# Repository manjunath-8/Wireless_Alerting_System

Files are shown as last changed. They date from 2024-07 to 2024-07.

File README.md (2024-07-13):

# Wireless Alerting System
## Abstract
This project presents the development and implementation of a wireless dashboard for real-time machine error monitoring using the Arduino IoT Cloud. The system aims to enhance operational efficiency and streamline error resolution across multiple departments within an industrial setting. Utilizing ESP32 microcontrollers, the dashboard collects and transmits machine error data wirelessly, providing instant updates accessible via mobile devices and desktops. The project features a custom-designed PCB and a 3D-printed case to house the electronics. Key functionalities include department-wide error dashboards, efficiency tracking using Google Sheets, and mobile accessibility for on-the-go monitoring. This innovative solution facilitates proactive maintenance, minimizes downtime, and improves overall productivity.

## Repository Structure
### Codes
This section contains the code necessary for the operation of the Wireless Alerting System. The repository is organized into two main subdirectories: Arduino IoT Cloud Sketch and Google Sheets App Script.

- **Arduino_IoT_Cloud**
In this subdirectory, you will find the code to be uploaded to the ESP32 microcontroller using the Arduino IoT Cloud platform. The code handles the collection of machine error data and its transmission to the cloud.
- **Google_Sheets_App_Script**
This subdirectory contains the Google Sheets App Script code, which is used to track efficiency and log machine errors in a Google Sheet.

### PCB Design Files
Schematic and layout files for the custom PCB design, including BOM (Bill of Materials) and Gerber files for manufacturing.
  
### Fusion360
STL files for 3D printing the custom-designed case for the electronics.

**Note:** Refer PPT, Report, Poster for other details. 

## Setting Up Arduino IoT Cloud

### 1. Adding Devices and Programming with Arduino IoT Cloud

1. **Create an Account and Setup**
   - Sign up for an Arduino IoT Cloud account if you haven't already.

2. **Create a New Thing**
   - Log into Arduino IoT Cloud.
   - Click on "Things" and then "Create a New Thing".
   - Name your device (e.g., ESP32), select the board (ESP32), and choose a connectivity type (Wi-Fi).

3. **Setting Up Variables**
   - Define variables for your project (e.g., error codes, timestamps).
   - Specify data types and any default values.

4. **Create Dashboards**
   - Design dashboards to visualize your variables in real-time.
   - Arrange widgets to display machine error data effectively.

5. **Programming the ESP32**
   - Write your Arduino sketch (`Arduino_IoT_Cloud_Sketch`) to read sensor data (e.g., machine error data) and update variables.
   - Use the Arduino IDE or Arduino IoT Cloud's online editor to upload your sketch to the ESP32.

6. **Testing**
   - Ensure your ESP32 is connected to Wi-Fi and transmitting data correctly.
   - Monitor the Arduino IoT Cloud dashboard to verify data reception.

## Integrating with Google Sheets App Script

### 2. Writing and Deploying Google Sheets App Scripts

1. **Create a Google Sheet**
   - Open Google Sheets and create a new spreadsheet.
   - Set up columns for error logs, timestamps, and any other relevant data.

2. **Enable Google Apps Script**
   - In Google Sheets, go to "Extensions" > "Apps Script" to open the script editor.

3. **Write the Error Logger Script**
   - Write a script (`Google_Sheets_App_Script`) to receive data from Arduino IoT Cloud.
   - Use functions like `doPost(e)` to handle incoming data via HTTP requests.
   - Parse incoming data and append it to your Google Sheets.
   
4. **Deploy the Scripts**
   - Save and deploy your scripts as a web app.
   - Set permissions to run the script as you (the owner) or anyone accessing the web app.
   - Obtain the deployment URL for later use in your Arduino IoT Cloud setup.

# Integration and Testing

1. **Connect Arduino IoT Cloud to Google Sheets**
   - Use the deployment URL of your Google Apps Script in Arduino IoT Cloud.
   - Configure the HTTP integration to send data from Arduino IoT Cloud to your Google Sheets App Script endpoint.

2. **Monitor and Debug**
   - Test the entire system to ensure data flows from ESP32 → Arduino IoT Cloud → Google Sheets correctly.
   - Use debugging tools in Arduino IoT Cloud and Google Sheets to troubleshoot any issues.

By following these steps, you can successfully integrate your Arduino IoT Cloud setup with Google Sheets, allowing for real-time logging and dashboarding of machine error data.

## License
This project is licensed under the MIT License - see the [LICENSE](LICENSE) file for details.

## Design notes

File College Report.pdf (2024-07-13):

## School of Electronics and Communication Engineering

## Minor-I Project Report

on

# WIRELESS ALERTING SYSTEM FOR INDUSTRIAL ENVIRONMENT

By:

1. Goutami Naragund | USN:01FE21BEC177
2. Manjunath Inamati | USN:01FE21BEC356
3. Chetan Paranatti | USN:01FE21BEC163

## Semester: VI, 2023-2024

## Under the Guidance of

## Saroja V Siddamal

1

KLE Technological University,

### HUBBALLL580031

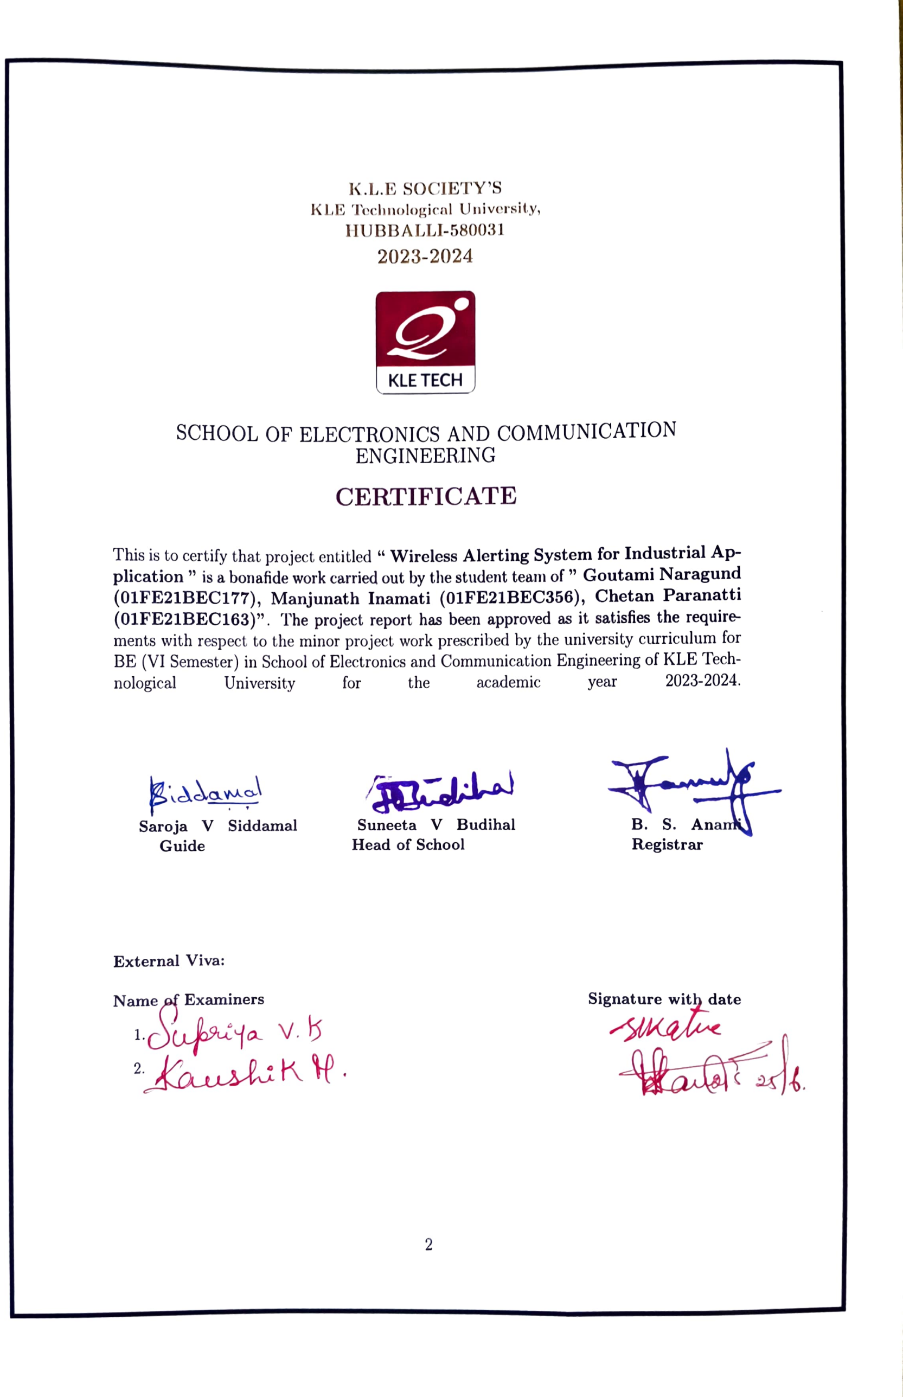
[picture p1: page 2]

# Badamal

### Saroja V Siddamal

Guide

# SCHOOL OF ELECTRONICS AND COMMUNICATION

## ENGINEERING

External Viva:

K.L.E SOCIETY'S

### Name af Examiners

This is to certify that project entitled 4 Wireless Alerting System for Industrial Ap plication " is a bonafide work carried out by the student team of " Goutami Naragund (01FE21BEC177), Manjunath Inamati (0IFE21BEC356), Chetan Paranatti

# (01FE21BEC163)". The project report has been approved as it satisfies the require

# ments with respect to the minor project work prescribed by the university curriculum for

# BE (VI Semester) in School of Electronics and Communication Engineering of KLE Tech

nological | University | for | the | academic

2023-2024

### KLE TECH

# dufaiya v.b

Kaushik .

# CERTIFICATE

Suneeta V Budihal
Head of School

2

year

### B. S. Anan

## Registrar

## Signature with date

2023-2024.

## ACKNOWLEDGMENT

We express our gratitude to the faculty and management for their professional guidance throughout the project’s completion. We would like to extend our thanks to Dr. Ashok Shettar, Vice-Chancellor at KLE Technological University, Hubballi, for their visionary leadership and unwavering support. Special thanks to Dr. Suneeta V Budihal, Professor and Head of SoECE, for providing us with direction and fostering our skills and academic growth. We thank our guide, Dr. Saroja V Siddamal, for their constant guidance during interactions and reviews. We acknowledge the reviewers for their valuable suggestions and inputs. Additionally, we express our thanks to the Project Coordinator Sushma Garawad and other faculty in-charges for their support throughout the completion of the project.

Goutami Naragund
Manjunath Inamati
Chetan Paranatti

3

## ABSTRACT

In this work, the implementation of wireless alerting system is carried out as per the requirements floated by the Spicer Industry. From the design of the circuit to the final product is carried out systematically and documented. All the components details and the external products used in the process are listed below. The built product is set up in the industry campus and working well in the real-time.

4

# Contents

1 Introduction | 9
2 System design | 13
3 Implementation details | 15
4 Alignment with SDG | 17
5 Implementation Results and Future scope | 19
References | 20

5

# List of Tables

1.1 Bill of materials | | 12
2.1 Morphological chart | | 14

6

# List of Figures

1.1 Pictorial representation of requirements | | 9
2.1 Functional block diagram | | 13
2.2 Final design | | 14
3.1 Flow chart | | 15
3.2 3D view of PCB | | 16
3.3 PCB Layout design | | 16
4.1 Sustainable Development Goals | | 17
5.1 Dashboard created using Arduino IoT Cloud | | 19
5.2 Google sheet entries and Mobile Notifications | | 20

7

# Chapter 1

# Introduction

In today’s fast-paced industrial environment, timely alerts are crucial for ensuring safety, maintaining operational efficiency, and preventing costly downtimes. Traditional wired alerting systems, while reliable, can be cumbersome and expensive to install and maintain. Wireless alerting systems offer a flexible and cost-effective alternative, providing ease of installation and scalability. With advances in wireless technology, it is now possible to develop robust alerting systems that can operate efficiently in various industrial settings.

## 1.1 Motivation

The industry that floated this project is currently facing challenges with their existing alerting systems, which are predominantly wired. These systems are not only expensive to install but also difficult to reconfigure when there are changes in the operational layout.There is a pressing need for a wireless alerting system that can overcome these limitations and provide reliable and timely alerts across the industrial plant.

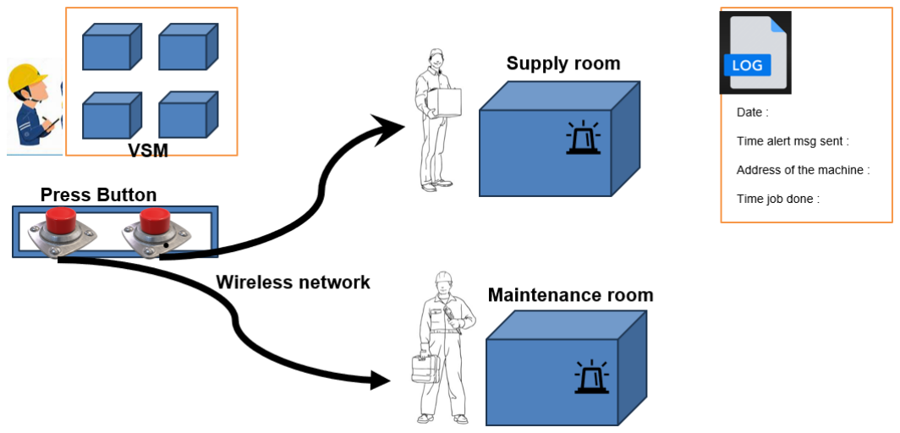
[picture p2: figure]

Figure 1.1: Pictorial representation of requirements.

8

## 1.2 Objectives

The primary objective of this project is to design and develop a wireless alerting system that meets the specific needs of the industry. The system should be:

- Reliable and accurate in providing timely alerts.
- Easy to install and maintain.
- Track the efficiency of the service provider.
- Track date and time and specifications of the alert message.

## 1.3 Literature survey

The existing literature and technological options for developing a wireless alerting system suitable for industrial applications were reviewed. Through our literature survey, we identified three primary technologies for wireless communications: GSM modules, Blynk, and Arduino IoT Cloud. After evaluating the advantages and limitations of each, we selected Arduino IoT Cloud for our project. Below is a detailed analysis of each option and the rationale behind our final choice.

1. GSM Modules
GSM (Global System for Mobile Communications) modules are widely used for wireless communication in various applications. They provide reliable long-range communication by leveraging the cellular network infrastructure. However, implementing a wireless alerting system using GSM modules in an industrial setting presents several challenges:
- High Cost: Each controller in the system requires a separate GSM module, significantly increasing the overall cost.
- Complexity: The need for multiple modules complicates the system architecture and maintenance.
- Scalability Issues: Expanding the system would require additional GSM modules, further escalating costs and complexity.
- Track date and time and specifications of the alert message.

Given these constraints, GSM modules were deemed unsuitable for our project

2. Blynk
Blynk is an Internet of Things (IoT) platform that allows users to create mobile and web applications for the Internet of Things. It supports various microcontrollers and communication protocols, providing an easy-to-use interface for developing IoT solutions. Despite its advantages, Blynk was not selected for the following reasons:
- Limited Customization: While Blynk is user-friendly, it offers limited flexibility for complex industrial applications that require extensive customization.
- Dependence on Third-Party Services: Blynk relies on third-party servers, which may pose reliability issues and potential security concerns for industrial applications where data integrity and system reliability are critical.

Due to these limitations, Blynk was not considered the optimal choice for our project.

9

3. Arduino IoT Cloud
Arduino IoT Cloud is a platform that enables the creation and management of IoT devices with ease. It supports various Arduino boards and provides a robust environment for building IoT applications. After careful consideration, we selected Arduino IoT Cloud for the following reasons:
- Ease of Integration: Arduino IoT Cloud seamlessly integrates with Arduino hardware, making it easier to develop and deploy the wireless alerting system.
- Scalability: The platform supports scalable solutions, allowing for future expansion without significant additional costs.
- Customization: It offers extensive customization options, enabling the development of tailored solutions to meet specific industrial requirements.
- Security and Reliability: Arduino IoT Cloud provides secure communication protocols and reliable performance, essential for industrial applications.

Based on these factors, Arduino IoT Cloud was determined to be the most suitable platform for developing our wireless alerting system

## 1.4 Problem statement

WIRELESS ALERTING SYSTEM FOR INDUSTRIAL ENVIRONMENT

## 1.5 Application in Societal Context

Our project aligns with several Sustainable Development Goals (SDGs) by promoting efficiency, inclusivity, innovation, and responsible resource management. Satisfies the requirements floated by the industry.

## 1.6 Project Planning and bill of materials

The project is divided into several key phases to systematically approach the development of the wireless alerting system. The first phase involves requirement analysis and a feasibility study. During this phase, specific requirements from the industry are identified, and a feasibility study is conducted. The second phase is system design, where the architecture of the wireless alerting system is designed, and appropriate hardware components and software tools are selected.

The third phase is development and integration. In this phase, the software for the alerting system is developed and integrated with the selected hardware.The fourth phase is testing and validation, where the system is tested under various scenarios to ensure reliability and accuracy. The system’s performance is validated against predefined criteria.

10

Table 1.1: Bill of materials.

Sl.No | Name | Cost | Quantity
1 | ESP32 Wroom | 450 | 1
2 | Emergency push button | 170 | 6
3 | Hi-Link 220V AC to 5V DC Converter | 230 | 1
4 | Hi-Link 220V AC to 3V3 DC Converter | 230 | 1
5 | PCB | 531 | 1

## 1.7 Organization of the report

- Chapter 2 consists of detailed steps involved in System design.
- Chapter 3 consists of process flow and final design.
- Chapter 4 consists of the alignment of our project towards SDGs.
- Chapter 5 consists of validation results.

11

# Chapter 2

# System design

Introducing a cutting-edge solution for managing maintenance and supply chain issues within a network of plants housing various machines. Each machine is outfitted with a display unit signaling its operational status: green for normal functioning and red for issues. To address maintenance or supply chain problems and others , every machine is equipped with six buttons. Upon activation, these buttons wirelessly notify the designated personnel, facilitating prompt resolution of the identified issue.

## 2.1 Functional block diagram

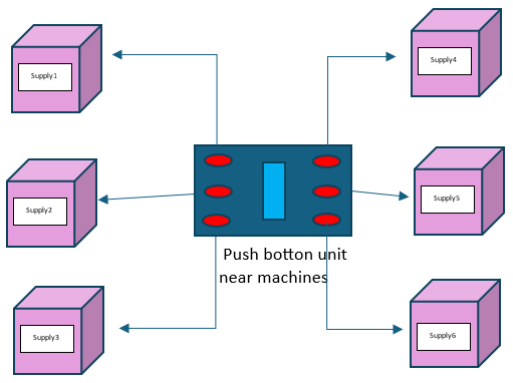
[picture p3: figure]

Figure 2.1: Functional block diagram.

12

## 2.2 Design alternatives

Each alternative involves different technologies and approaches, each with its own set of advantages and limitations. By evaluating these design alternatives, we can ensure that the final system meets the specific needs of the industry in terms of reliability, scalability, cost-effectiveness, and ease of implementation.

In this project, we examined multiple options for wireless communication and microcontroller platforms to determine the best combination for our system. This thorough evaluation process allowed us to make an informed decision on the optimal design for our wireless alerting system.

Table 2.1: Morphological chart

Functions/Means | Option 1 | Option 2 | Option 3
Wireless Communication | GSM Module | Blynk | Arduino IoT cloud
Micro-Controller | ESP32 | Raspberry Pi | ESP8266

## 2.3 Final design

Wireless Communication : Arduino IoT Cloud
Arduino IoT Cloud is a platform that enables the creation and management of IoT devices with ease. It supports various Arduino boards and provides a robust environment for building IoT applications.
Micro-Controller : ESP32 Wroom32
The unique antenna design of ESP32-WROOM-DA has resulted in the module’s excellent wireless communication, even under difficult circumstances. Thus, makers using ESP32-WROOM-DA can now develop IoT applications that need stable connectivity over a broad spectrum, or deploy Wi-Fi in challenging and hazardous environments, or overcome communication problems in Wi-Fi-dead spots.

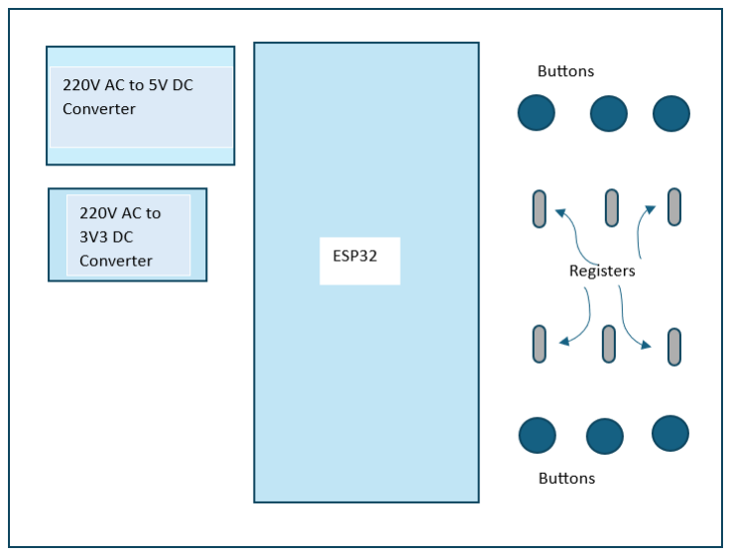
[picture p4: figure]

Figure 2.2: Final design

13

# Chapter 3

# Implementation details

## 3.1 Specifications and Final system architecture

schematic Hakbekuuu |

## 3.2 Flowchart

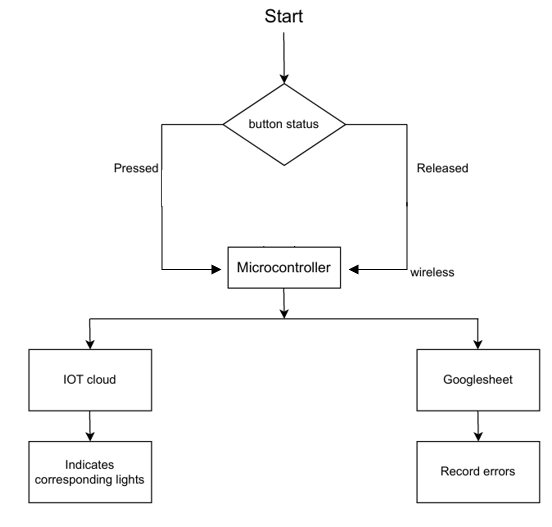
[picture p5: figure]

Figure 3.1: Flow chart

After finalizing the design and thoroughly testing all components on a zero PCB (prototype board), we proceeded to the PCB fabrication stage. This step is crucial for transitioning from a prototype to a fully functional and reliable product. The design was meticulously reviewed to ensure it met all performance and reliability requirements before sending it for fabrication. The Figure 3.2 and Figure 3.3 showcase the 3D view and layout of the PCB. These files are essential for the PCB fabrication process, providing a detailed blueprint of the board’s structure and component placement.

14

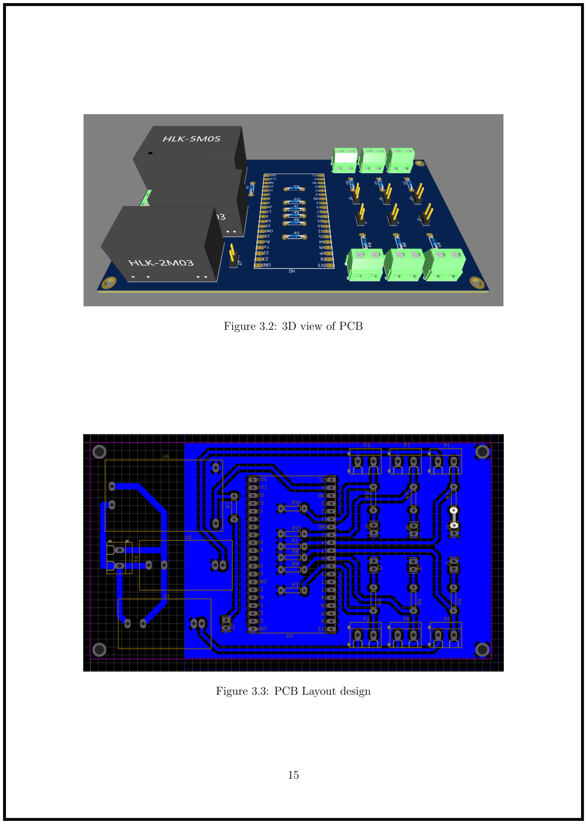
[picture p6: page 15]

Figure 3.2: 3D view of PCB

Figure 3.3: PCB Layout design

15

# Chapter 4

# Alignment with SDG

## 4.1 Introduction to SDGs

The Sustainable Development Goals (SDGs), established by the United Nations in 2015, represent a global call to action to end poverty, protect the planet, and ensure prosperity for all by 2030. Comprising 17 interconnected goals, the SDGs address a wide range of critical issues, including social, economic, and environmental dimensions of sustainable development. Their importance cannot be overstated, as they provide a comprehensive framework for addressing the most pressing challenges facing humanity today.

Our project “Wireless Alerting System for Industrial Environment” aligns with several Sustainable Development Goals (SDGs) by promoting efficiency, inclusivity, innovation, and responsible resource management.

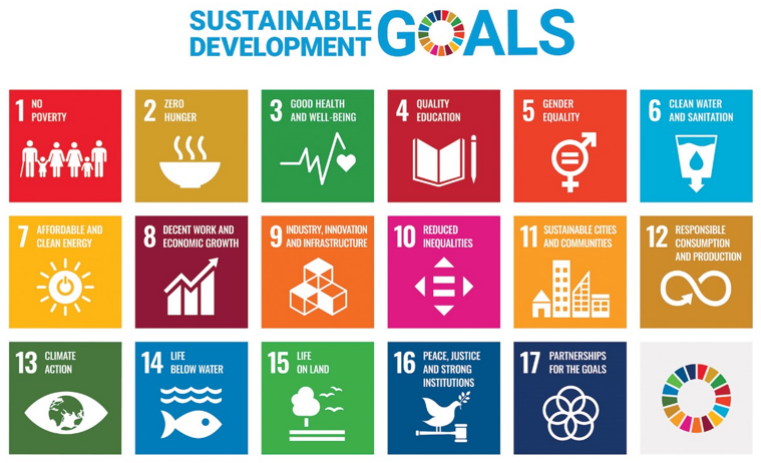
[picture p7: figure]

Figure 4.1: Sustainable Development Goals

16

- SDG 9: Industry, Innovation, and Infrastructure - This goal focuses on building resilient infrastructure, promoting inclusive and sustainable industrialization, and fostering innovation. Our project directly aligns with this goal by improving industrial infrastructure through monitoring and alert systems.
- SDG 12: Responsible Consumption and Production - This goal aims to ensure sustainable consumption and production patterns. Our project contributes to this goal by optimizing equipment usage, reducing unnecessary downtime, and minimizing resource waste through timely maintenance alerts.
- SDG 8: Decent Work and Economic Growth- Industrial equipment monitoring systems help create employment opportunities in the maintenance, repair, and supply chain management sectors. By improving the productivity and reliability of industrial processes, these systems contribute to economic growth and the creation of sustainable livelihoods.

By addressing these SDGs, your project can demonstrate its commitment to promoting sustainable development and contributing to global efforts to tackle pressing societal and environmental challenges.

17

# Chapter 5

# Implementation Results and Future scope

## 5.1 Implementation Results

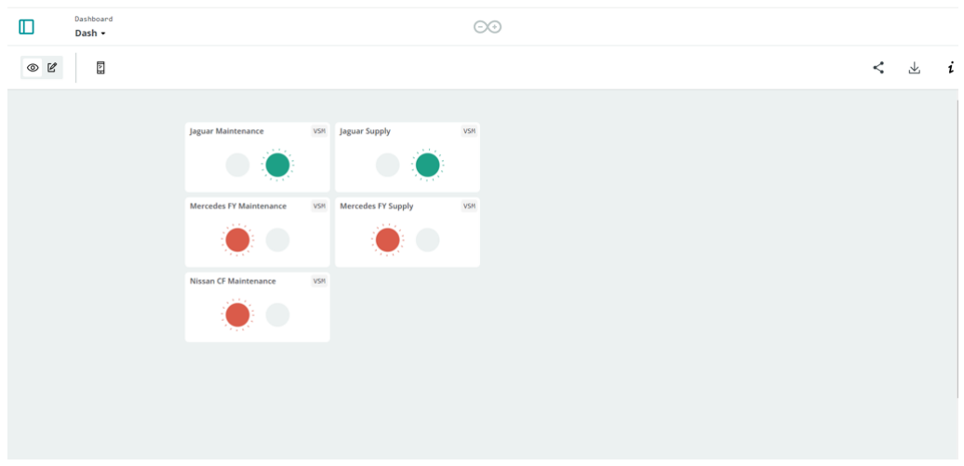
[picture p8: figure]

Figure 5.1: Dashboard created using Arduino IoT Cloud

Finally, we have developed a comprehensive dashboard that provides real-time monitoring of the push button status in our wireless alerting system. This dashboard shown in Figure 5.1 is designed to be user-friendly and intuitive, ensuring that users can quickly and easily understand the current state of the system.

The Figure 5.2 illustrates two critical components of our wireless alerting system: the entries of alerts in Google Sheets and the notifications popping up on our mobile devices. These features enhance the system’s efficiency and ensure that alerts are promptly and accurately communicated to the relevant users.
The Google Sheets integration allows for real-time logging and tracking of all alert events. Each time a push button is pressed, an entry is automatically created in the Google Sheet. Simultaneously, our system ensures that real-time notifications are sent to users’ mobile devices whenever an alert is triggered.

18

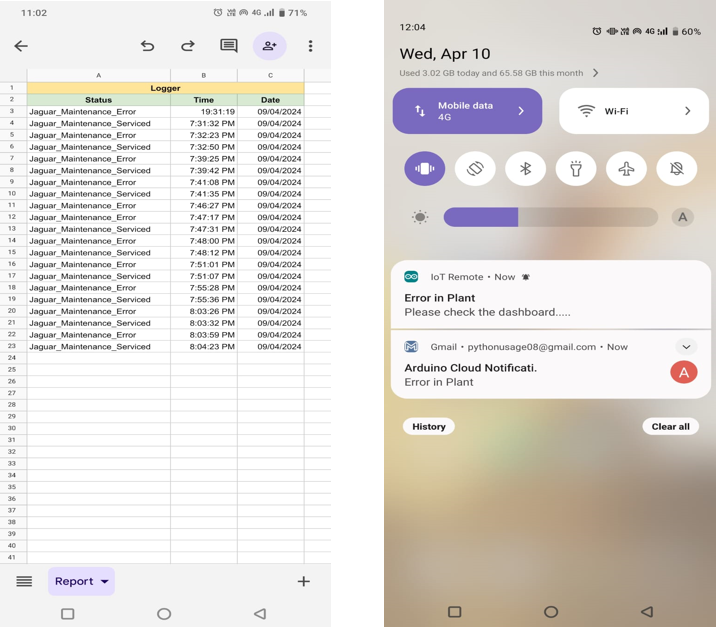
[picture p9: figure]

Figure 5.2: Google sheet entries and Mobile Notifications

## 5.2 Future scope

The wireless alerting system developed in this project holds significant potential for future enhancements and applications. As technology continues to advance and industrial needs evolve, several areas can be explored to further improve and expand the system’s capabilities. Here are some potential future developments:

- Enhanced Data Analytics
Incorporating advanced data analytics and machine learning algorithms can help in predictive maintenance and trend analysis. By analyzing historical data, the system can predict potential failures before they occur and optimize maintenance schedules, thus reducing downtime and maintenance costs.
- Improved User Interface and Mobile App Development
Enhancing the user interface for better user experience and developing dedicated mobile applications can improve accessibility and ease of use. Mobile apps can provide real-time notifications, system status updates, and allow users to interact with the system directly from their smartphones or tablets.
- Integration with Existing Industrial Systems
Ensuring compatibility and seamless integration with existing industrial systems (e.g., SCADA, ERP) can provide a more comprehensive monitoring and management solution. This will enable the wireless alerting system to work in conjunction with other industrial control systems, providing a unified platform for monitoring and control.

19

# Bibliography

20

13%

# SIMILARITY INDEX

12%

# INTERNET SOURCES

3%

# PUBLICATIONS

%

# STUDENT PAPERS

1 3%

2 2%

3 2%

4 1%

5 1%

6 1%

7 <1%

8 <1%

9 <1%

# try-1

## ORIGINALITY REPORT

## PRIMARY SOURCES

# www.slideshare.net

# Internet Source

# community.apachefriends.org

# Internet Source

# www.coursehero.com

# Internet Source

# www.rhydolabz.com

# Internet Source

# ijip.in

# Internet Source

# fastercapital.com

# Internet Source

# raw.githubusercontent.com

# Internet Source

# www.cse.ust.hk

# Internet Source

# Rohan Garg, B Dastagiri Reddy. "IoT Smart Plug based on ESP8266 Wi-Fi Chip"

, 2022 3rd

10 <1%

11 <1%

12 <1%

13 <1%

14 <1%

15 <1%

# Exclude quotes On Exclude bibliography On

# Exclude matches < 5 words

# International Conference on Smart Electronics and Communication (ICOSEC), 2022

# Publication

# publisher.uthm.edu.my

# Internet Source

# www.robotics.org.za

# Internet Source

# eprints.uthm.edu.my

# Internet Source

# usermanual.wiki

# Internet Source

# terrapass.com

# Internet Source

Hatem Taha AbuEltayef, Khaldoun S.

# AbuAlhin, Khalil M. Alastal. "Addressing nonrevenue water as a global problem and its interlinkages with sustainable development goals"

# , Water Practice & Technology, 2023

# Publication

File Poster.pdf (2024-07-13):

## Project Title: Wireless Alerting System for Industrial Application

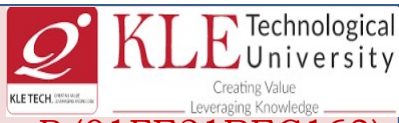
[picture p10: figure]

Team Members: Goutami N (01FE21BEC177), Manjunath I (01FE21BEC356), Chetan P (01FE21BEC163)

## Guide: Saroja V Siddamal

## Need statement

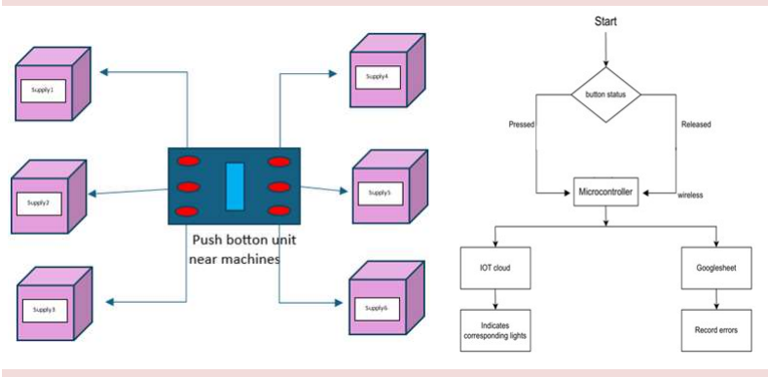
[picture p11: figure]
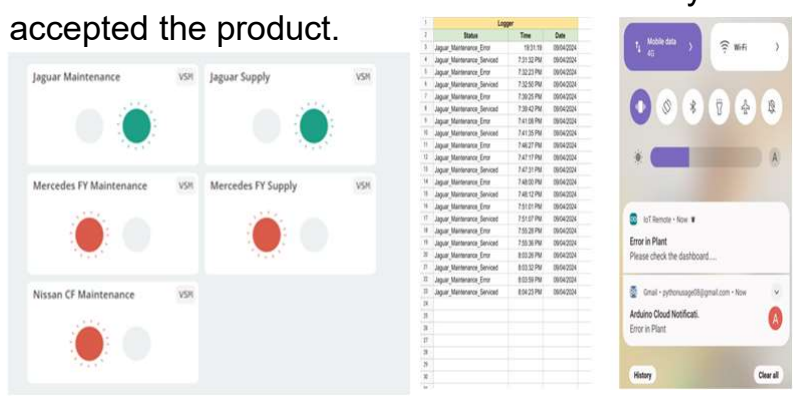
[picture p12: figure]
accepted the product.
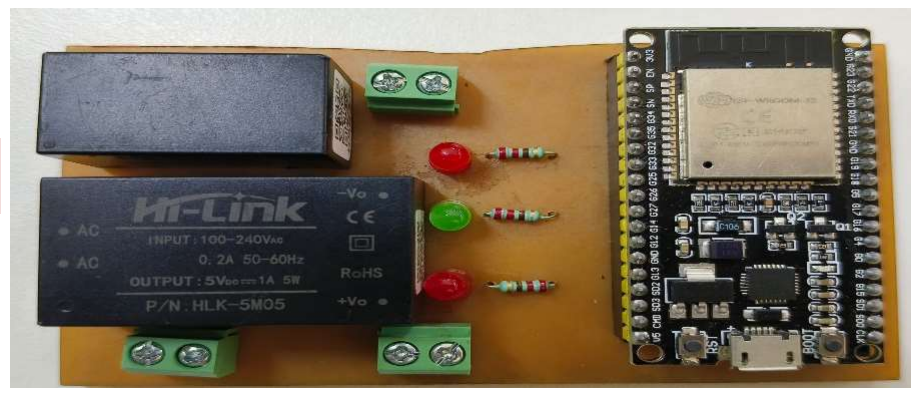
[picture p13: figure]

School Of Electronics and Communication Engineering | Team No: 03 | Minor Project I -2023-24

Develop a wireless alerting system that
- Is reliable and accurate in providing timely alerts. Easy to install and maintain.
- Track the efficiency of the service provider.
- Track the date, time, and origin of the alert message

### 1. The existing literature and technological

options for developing a wireless alerting system suitable for industrial applications were reviewed.

### 2. Suitable Microcontroller which has the Wi-Fi

module with efficient cost was reviewed.

System Block Diagram | SDG Connect

## Literature Survey

Alerting System for Industrial Application

## Problem statement

### 1. Design the circuit that works on 220V AC

supply, takes inputs from the push buttons, and sends data to the dashboard, and Google Sheets using ESP32.

## Objective

### 1. ESP32 wroom32

2. 220V AC to 5V DC converter
3. 220V AC to 3.3V DC converter

### 4. Push Botton 5. Arduino IoT cloud

## Requirements

## System Setup

- Choosing the correct components going into the circuit as well as the cloud service available.
- Solving all the problems that occurred while using wired systems.
- Resolved the issue of tracking the efficiency of each machine and the efficiency of workers.

## Challenges and Considerations

The project can help in addressing SDGs related to
- | SDG 9: Industry, Innovation, and Infrastructure. • | SDG12: Responsible Consumption and
Production. • | SDG 8: Decent Work and Economic Growth.

The product is working as per the requirements in the industrial environment. The Industry has

## Results

## Conclusion and Future Scope

In conclusion we are able to build a complete system which satisfies the industry needs. The project gave us lots of learnings and in-hand experience of working with the Industry. The product built is working well in the Industry environment and helps the workers to detect the need and efficiency of each machine placed in a plant. It also helps the manager to track service providers efficiency.

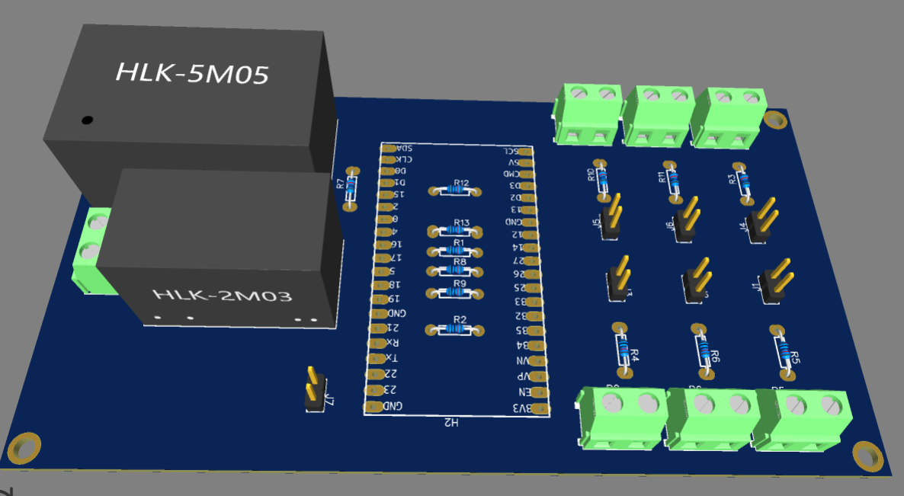
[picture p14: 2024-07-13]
EasyEDA/3d view.png

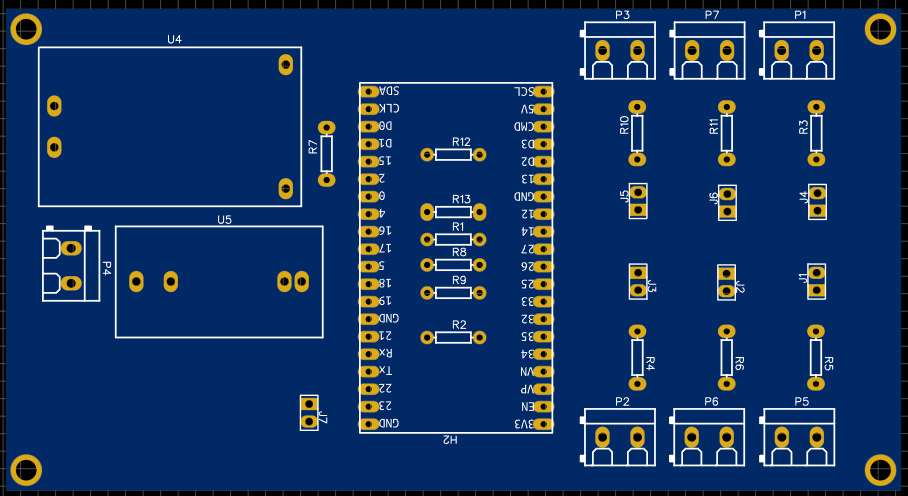
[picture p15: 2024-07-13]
EasyEDA/Top_View.png

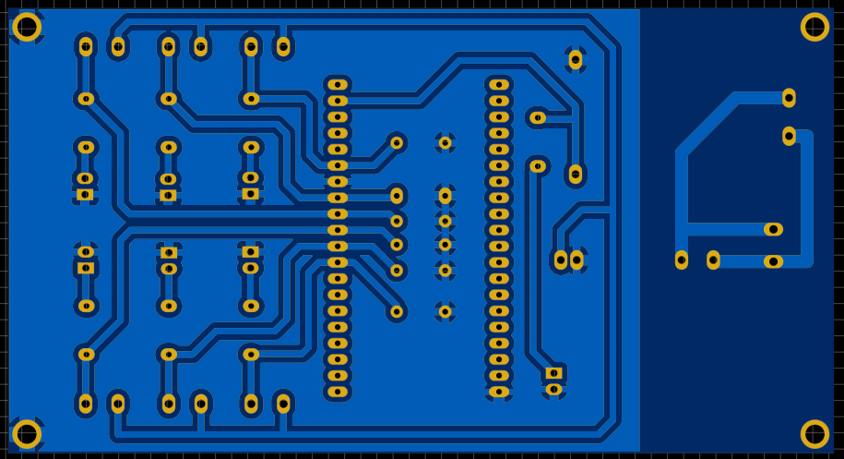
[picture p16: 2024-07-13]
EasyEDA/Bottom_View.png

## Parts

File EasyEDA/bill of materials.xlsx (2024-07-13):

Component | Quantity | Price | Total
ESP32 Wroom32 | 1 | 329 | 329
220v AC to 3.3v DC Hilink Converter Module (2W) | 1 | 193 | 193
220v AC to 5v DC Hilink Converter Module (5W) | 1 | 207 | 207
Emergency push button | 6 | 150 | 900
PCB Fabrication | 1 | 450 | 450
3.3v leds | 7 | 5 | 35
2 Terminal screw headers | 7 | 5 | 35
Female headers strip (40x1) | 1 | 8 | 8
220E resistors | 7 | 5 | 35
4.7K resistors | 6 | 5 | 30
2 pin RMC connector with Female | 7 | 10 | 70
 |  |  | 2292

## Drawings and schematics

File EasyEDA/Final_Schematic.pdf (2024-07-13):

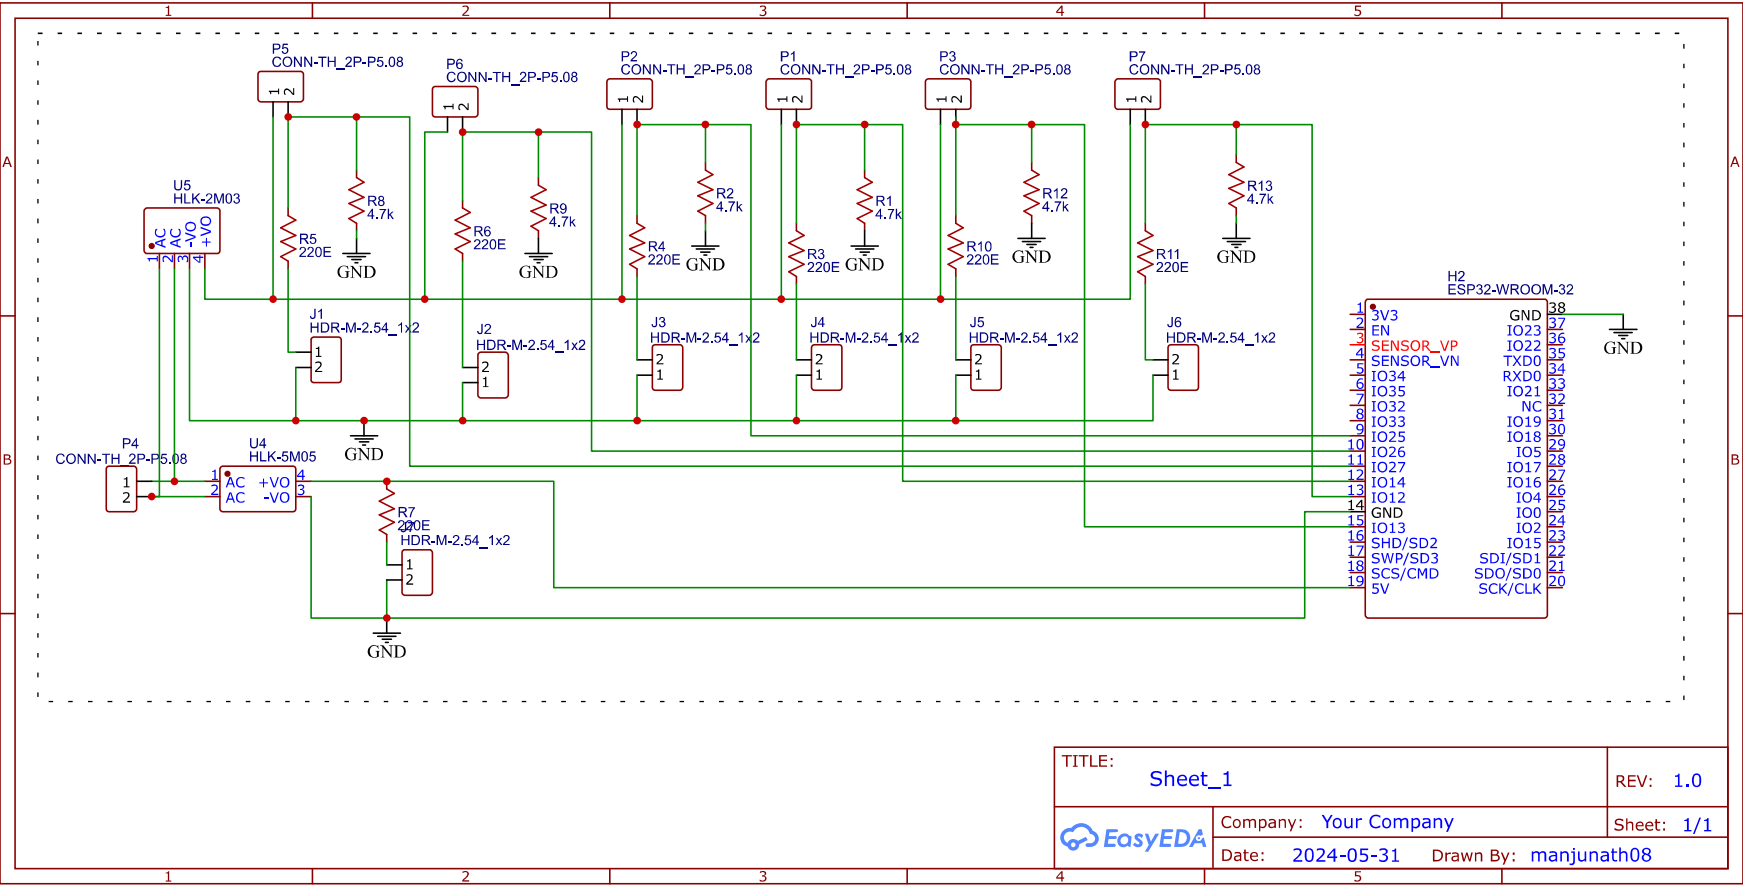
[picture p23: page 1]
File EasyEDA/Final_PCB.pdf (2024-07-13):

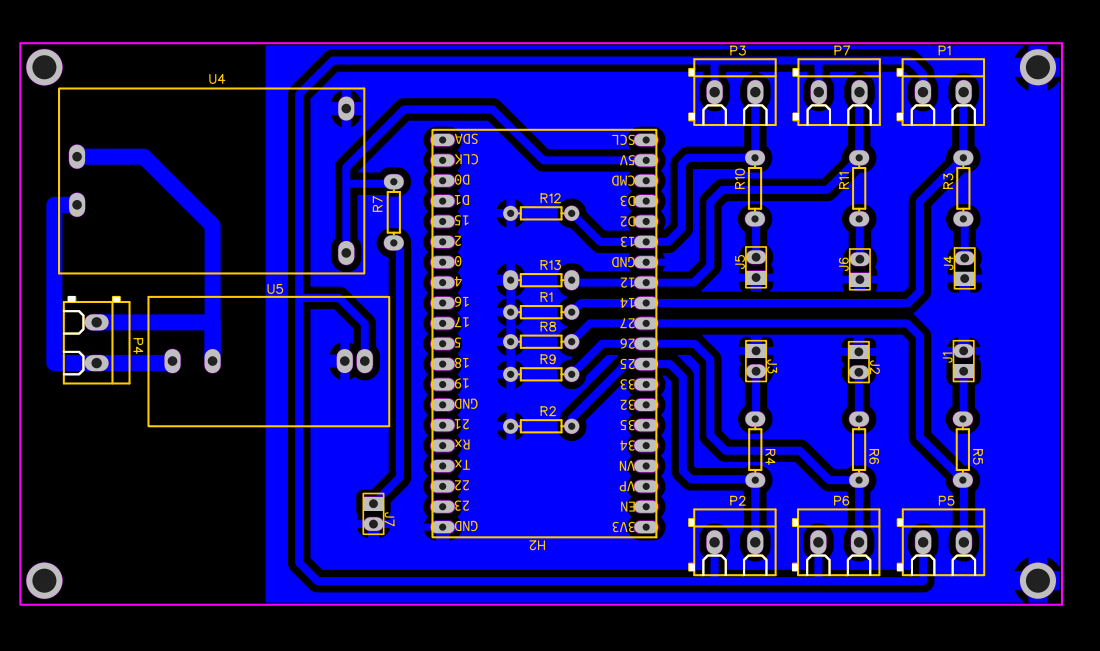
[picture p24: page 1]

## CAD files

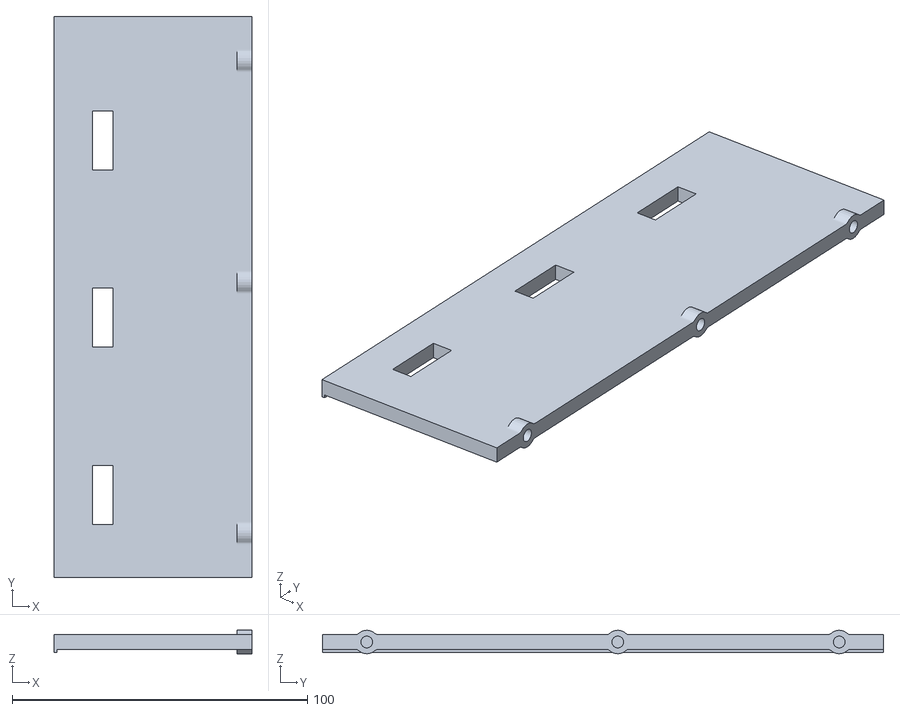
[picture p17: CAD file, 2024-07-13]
Fusion360/STL Files/middle3.stl
67.0 x 190.0 x 8.00

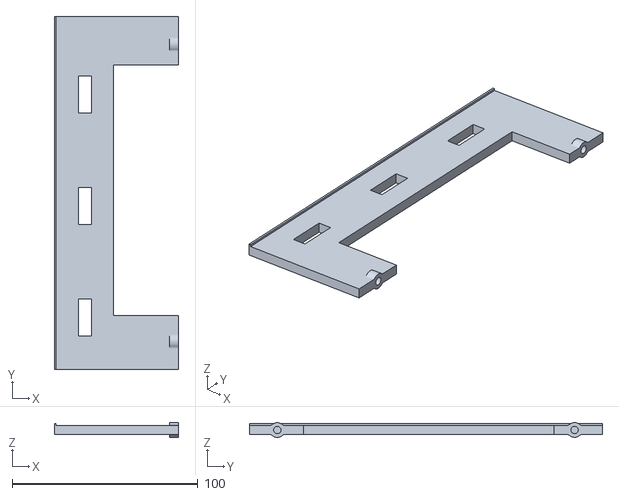
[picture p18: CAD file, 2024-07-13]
Fusion360/STL Files/middle1.stl
67.0 x 190.0 x 8.04

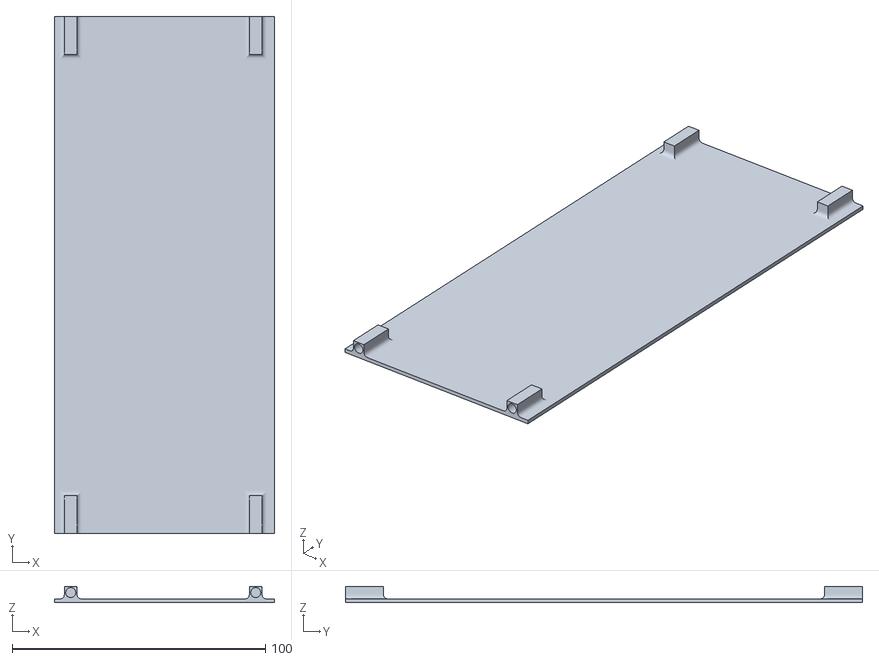
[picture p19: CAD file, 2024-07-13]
Fusion360/STL Files/side4.stl
87.0 x 204.0 x 6.50

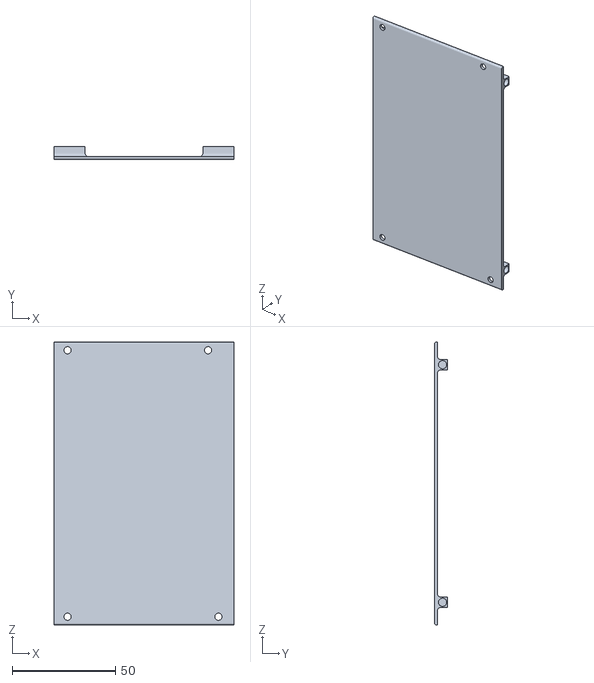
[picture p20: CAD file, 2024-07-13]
Fusion360/STL Files/side3.stl
87.0 x 6.50 x 137.0

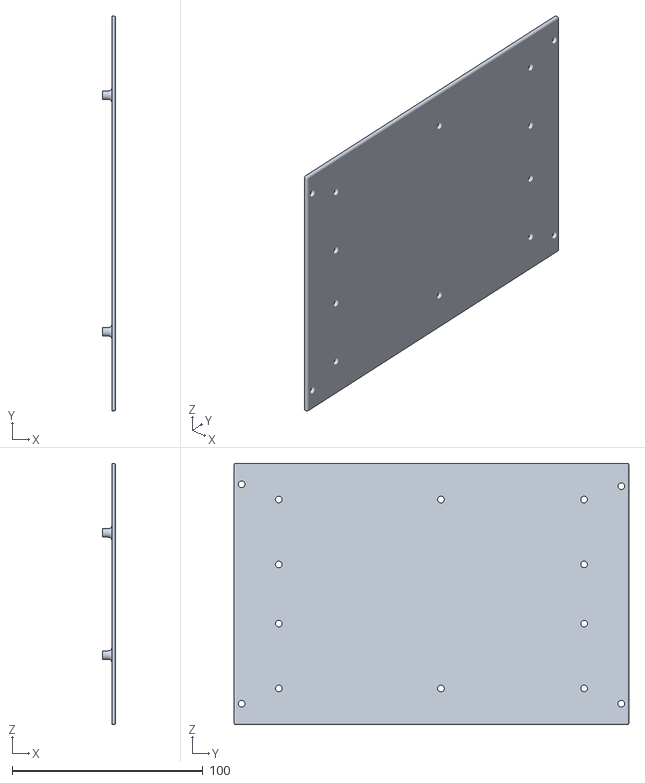
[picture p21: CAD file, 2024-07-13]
Fusion360/STL Files/bottom.stl
7.00 x 207.0 x 137.0

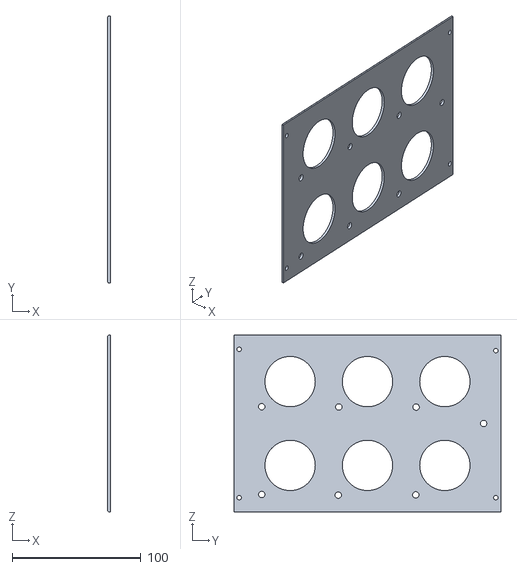
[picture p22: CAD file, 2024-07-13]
Fusion360/STL Files/top.stl
2.00 x 207.0 x 137.0

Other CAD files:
Fusion360/STL Files/middle2.stl
Fusion360/STL Files/middle4.stl
Fusion360/STL Files/side1.stl
Fusion360/STL Files/side2.stl
Fusion360/Box.f3d
